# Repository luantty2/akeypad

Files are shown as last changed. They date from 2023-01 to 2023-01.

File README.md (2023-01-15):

# akeypad

8khz polling rate keypad, uses STM32F405 and USB3300, powered by QMK.

This project is just a prototype, cases, plates and other keyboard components are not included.

akeypad

## PCB

pcb_2

## Firmware

The code can be found on my [Fork](https://github.com/luantty2/qmk_firmware/tree/qmk_master_build_2022q4/keyboards/akeypad).

## Bootloader

STM32f405/7xx should comes with a built-in bootloader, but sadly it doesn't seem to work on USB HS interface, if someone uses the default bootloader, he has to manually switch to FS port to upload firmware, then switch back to HS port to use his keyboard.

To address the issue, we can use a mux chip with tinyuf2 bootloader to automatically do that trick, then you don't bother switching port.

The mux chip we used here is TS3USB221, connect its 'S' pin to B14 of STM32. In normal operation, pull the pin to low to select HS interface, in bootloader mode, write this pin to high to select FS interface.

The tinyuf2 bootloader code can be found [here](https://github.com/luantty2/tinyuf2/tree/master_build/ports/stm32f4/boards/akeypad), if you wish to change B14 to other pin, you can modify it in `board.h`.

```c
//--------------------------------------------------------------------+
// Custom GPIO, used for USB mux
//--------------------------------------------------------------------+

#define CUSTOM_GPIO_PORT      GPIOB
#define CUSTOM_GPIO_PIN       GPIO_PIN_14
```

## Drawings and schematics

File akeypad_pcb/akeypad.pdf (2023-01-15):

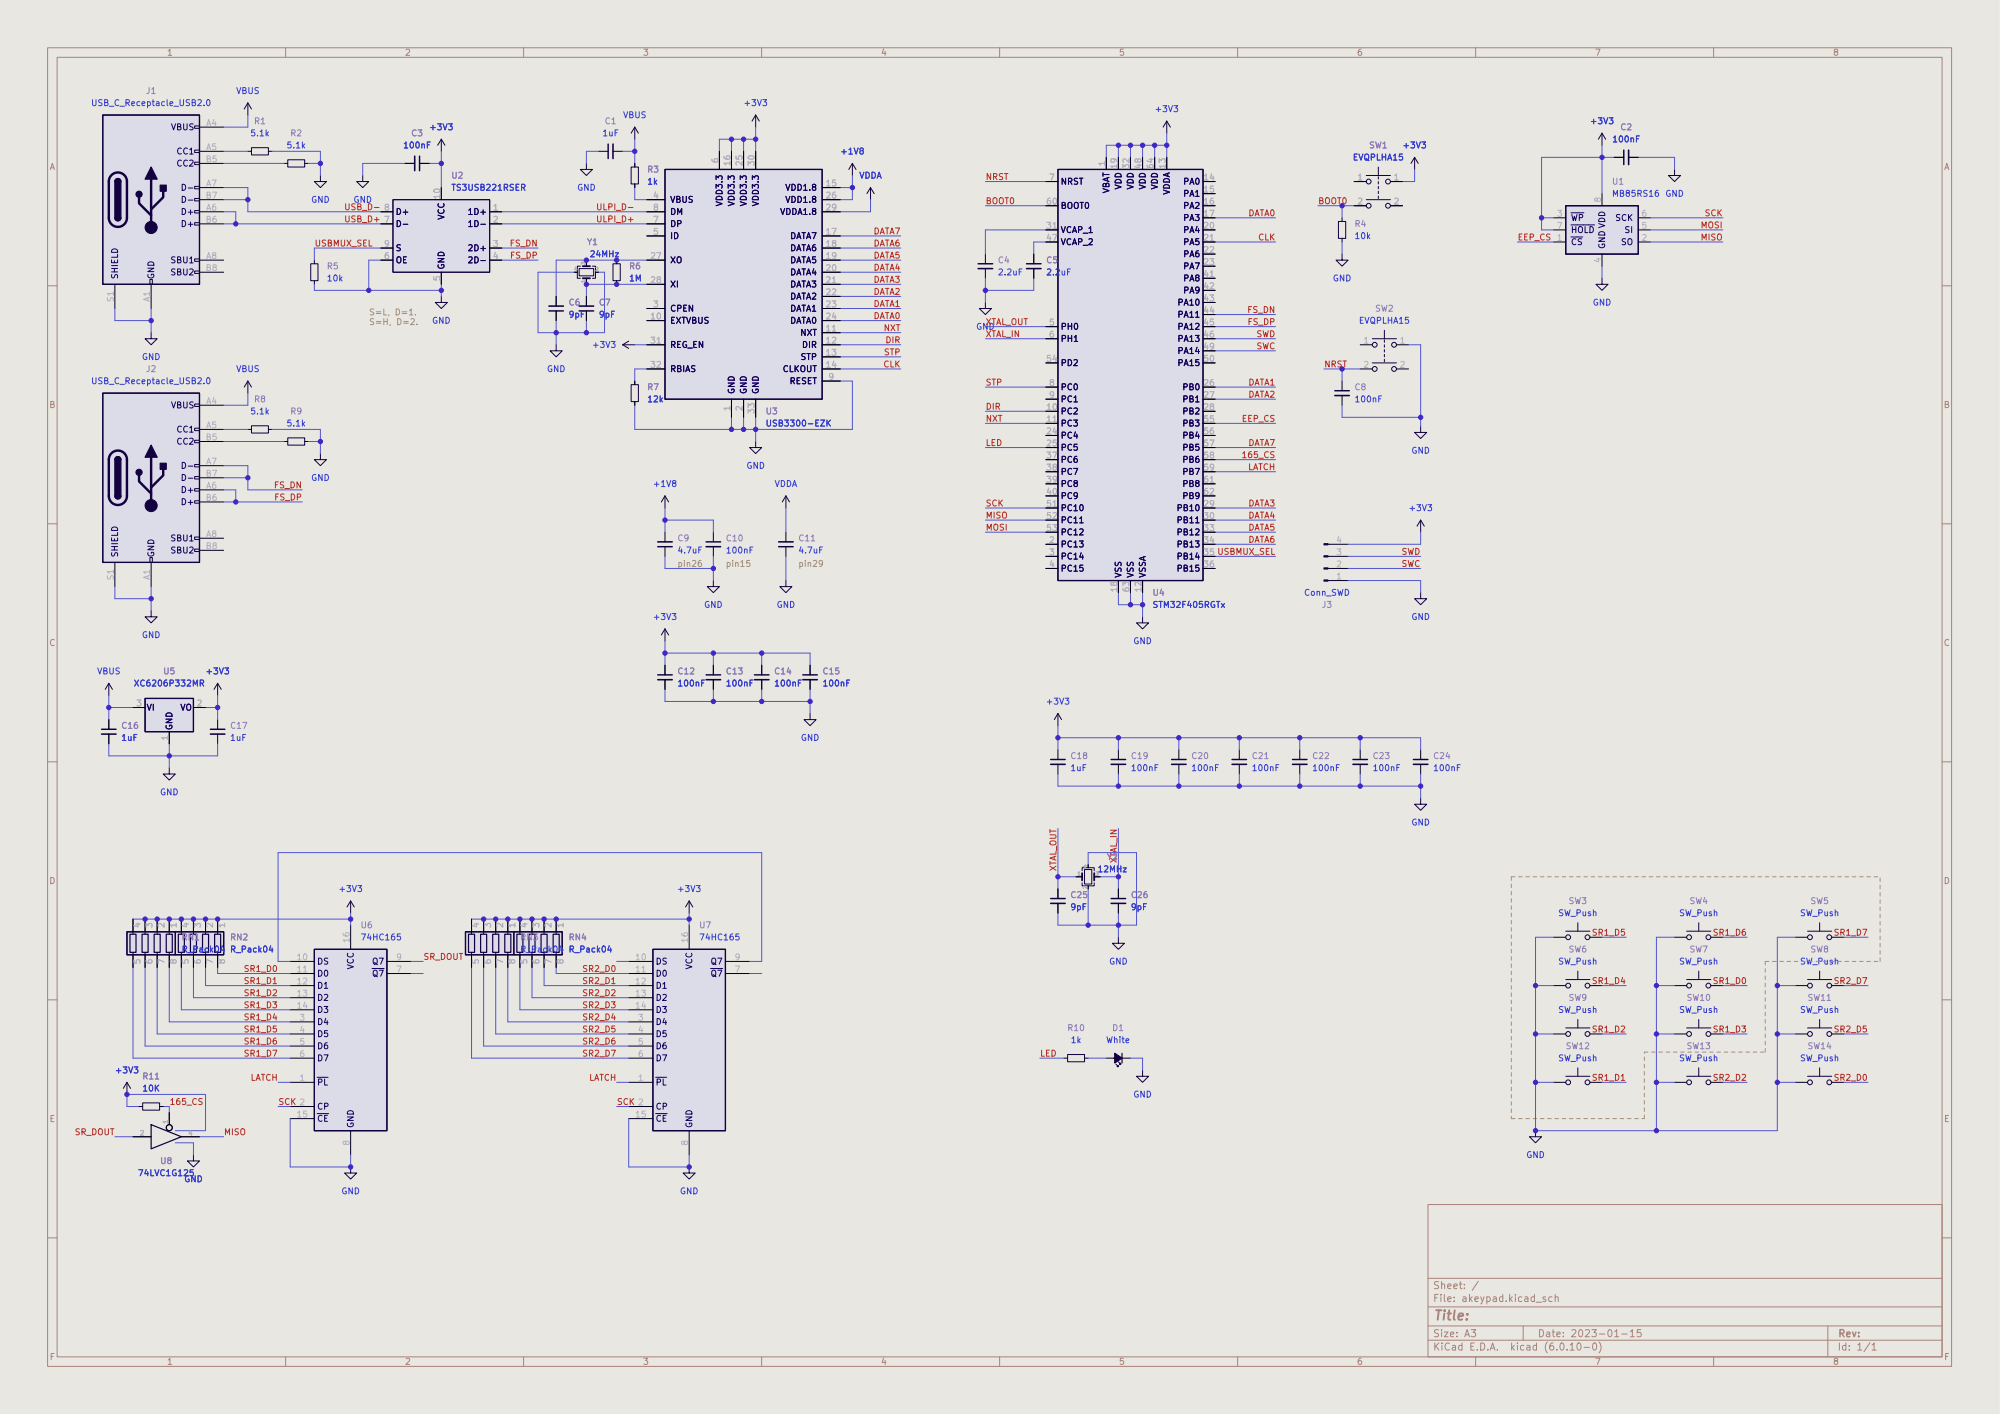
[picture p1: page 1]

1 PC2 10 PC3 11 VSSA 12 VDDA 13 PA0 14 PA1 15 PA2 16 PA3 17 VSS 18 VDD 19 PC13 2 PA4 20 PA5 21 PA6 22 PA7 23 PC4 24 PC5 25 PB0 26 PB1 27 PB2 28 PB10 29 PC14 3 PB11 30 VCAP_1 31 VDD 32 PB12 33 PB13 34 PB14 35 PB15 36 PC6 37 PC7 38 PC8 39 PC15 4 PC9 40 PA8 41 PA9 42 PA10 43 PA11 44 PA12 45 PA13 46 VCAP_2 47 VDD 48 PA14 49 PH0 5 PA15 50 PC10 51 PC11 52 PC12 53 PD2 54 PB3 55 PB4 56 PB5 57 PB6 58 PB7 59 PH1 6 BOOT0 60 PB8 61 PB9 62 VSS 63 VDD 64 NRST 7 PC0 8 PC1 9 U4STM32F405RGTx SR1_D3

1 EXTVBUS 10 NXT 11 DIR 12 STP 13 CLKOUT 14 VDD1.8 15 VDD3.3 16 DATA7 17 DATA6 18 DATA5 19 GND

2 DATA4 20 DATA3 21 DATA2 22 DATA1 23 DATA0 24 VDD3.3 25 VDD1.8 26 XO 27 XI 28 VDDA1.8 29 CPEN 3 VDD3.3 30 REG_EN 31 RBIAS 32 GND 33 VBUS 4

6 DP 7 DM 8 RESET 9 U3USB3300-EZK

6 DP 7 DM 8 RESET 9 VDDA

1 PC2 10 PC3 11 VSSA 12 VDDA 13 PA0 14 PA1 15 PA2 16 PA3 17 VSS 18 VDD 19 PC13 2 PA4 20 PA5 21 PA6 22 PA7 23 PC4 24 PC5 25 PB0 26 PB1 27 PB2 28 PB10 29 PC14 3 PB11 30 VCAP_1 31 VDD 32 PB12 33 PB13 34 PB14 35 PB15 36 PC6 37 PC7 38 PC8 39 PC15 4 PC9 40 PA8 41 PA9 42 PA10 43 PA11 44 PA12 45 PA13 46 VCAP_2 47 VDD 48 PA14 49 PH0 5 PA15 50 PC10 51 PC11 52 PC12 53 PD2 54 PB3 55 PB4 56 PB5 57 PB6 58 PB7 59 PH1 6 BOOT0 60 PB8 61 PB9 62 VSS 63 VDD 64 NRST 7 PC0 8 PC1 9C5

4 SI 5 SCK 6 ~{HOLD} 7 VDD

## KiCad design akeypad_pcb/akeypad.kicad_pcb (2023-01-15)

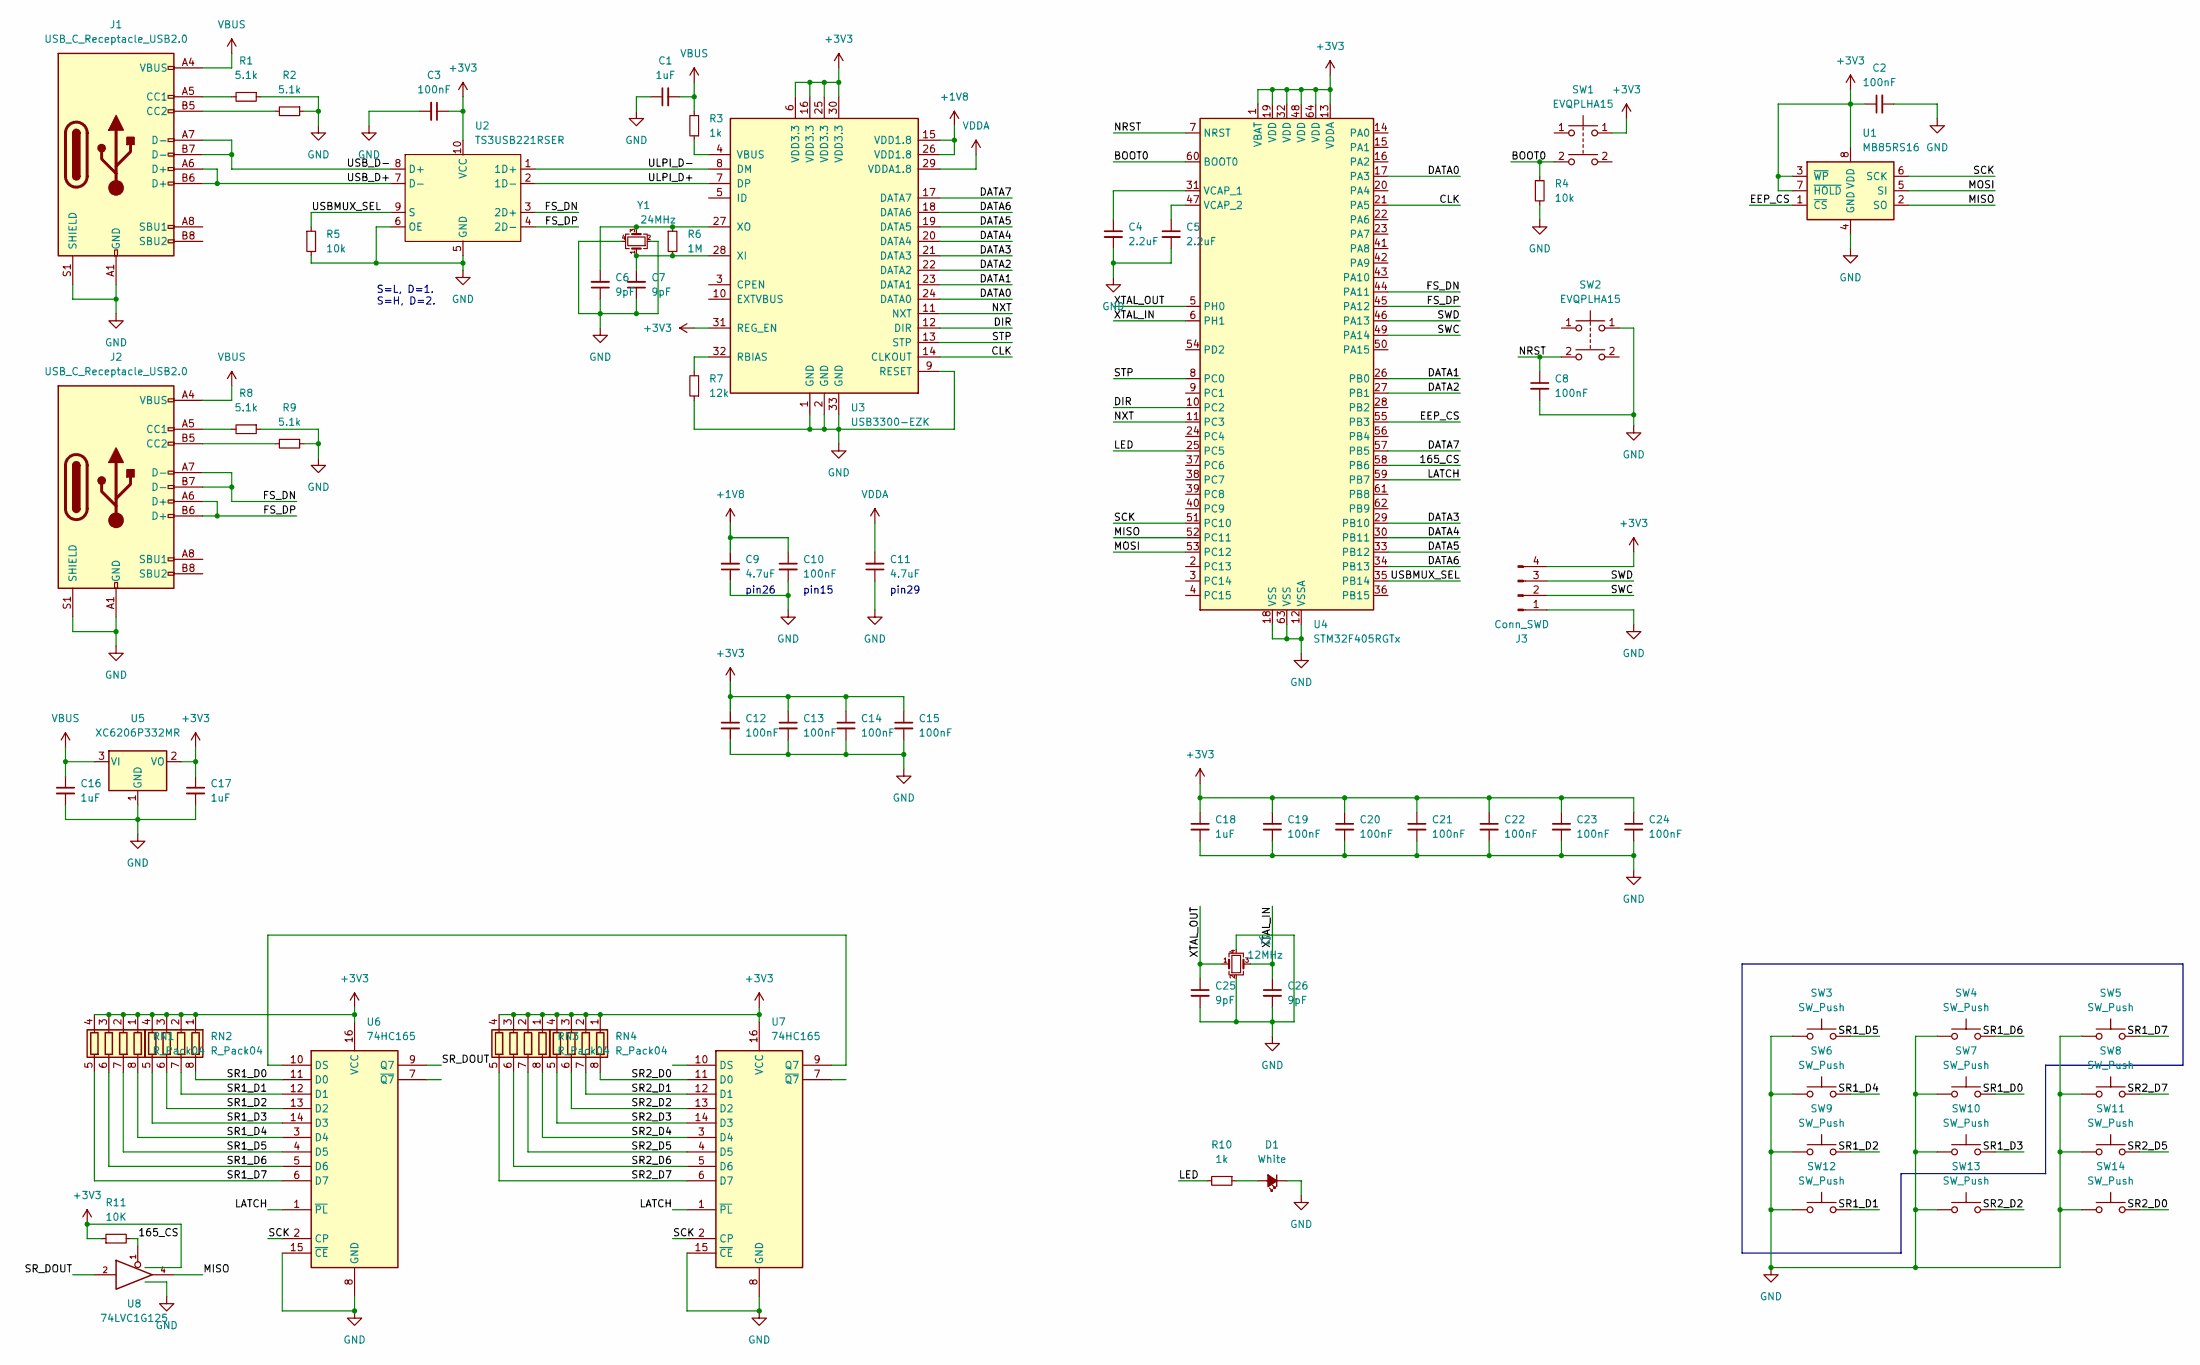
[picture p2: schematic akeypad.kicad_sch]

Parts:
C1, C16, C17, C18: 1uF; C_0603_1608Metric
C2, C3, C8, C10, C12, C13, C14, C15, C19, C20, C21, C22, C23, C24: 100nF; C_0402_1005Metric
C4, C5: 2.2uF; C_0603_1608Metric
C6, C7, C25, C26: 9pF; C_0402_1005Metric
C9, C11: 4.7uF; C_0603_1608Metric
D1: White; LED_0402_1005Metric
J1, J2: USB_C_Receptacle_USB2.0; USB_C_Receptacle_HRO_TYPE-C-31-M-12
J3: Conn_SWD; PinHeader_1x04_P1.27mm_Vertical
R1, R2, R8, R9: 5.1k; R_0402_1005Metric
R3, R10: 1k; R_0402_1005Metric
R4, R5: 10k; R_0402_1005Metric
R6: 1M; R_0402_1005Metric
R7: 12k; R_0402_1005Metric
R11: 10K; R_0402_1005Metric
RN1, RN2, RN3, RN4: R_Pack04; R_Array_Convex_4x0603
SW1, SW2: EVQPLHA15; SW_SPST_Panasonic_EVQPL_3PL_5PL_PT_A15
SW3, SW4, SW5, SW6, SW7, SW8, SW9, SW10, SW11, SW12, SW13, SW14: SW_Push; MXOnly-1U-NoLED
U1: MB85RS16; SOIC-8_3.9x4.9mm_P1.27mm
U2: TS3USB221RSER; UQFN-10
U3: USB3300-EZK; QFN-32-1EP_5x5mm_P0.5mm_EP3.45x3.45mm
U4: STM32F405RGTx; LQFP-64_10x10mm_P0.5mm
U5: XC6206P332MR; SOT-23
U6, U7: 74HC165; SOP-16_3.9x9.9mm_P1.27mm
U8: 74LVC1G125; SOT-23-5
Y1: 24MHz; Crystal_SMD_2016-4Pin_2.0x1.6mm
Y2: 12MHz; Crystal_SMD_3225-4Pin_3.2x2.5mm

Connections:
+1V8: C9.2, C10.1, U3.15 (VDD1.8), U3.26 (VDD1.8)
+3V3: C2.1, C3.1, C12.1, C13.1, C14.1, C15.1, C17.1, C18.1, C19.1, C20.1, C21.1, C22.1, C23.1, C24.1, J3.4, R11.1, RN1.1 (R1.1), RN1.2 (R2.1), RN1.3 (R3.1), RN1.4 (R4.1), RN2.1 (R1.1), RN2.2 (R2.1), RN2.3 (R3.1), RN2.4 (R4.1), RN3.1 (R1.1), RN3.2 (R2.1), RN3.3 (R3.1), RN3.4 (R4.1), RN4.1 (R1.1), RN4.2 (R2.1), RN4.3 (R3.1), RN4.4 (R4.1), SW1.1, U1.3 (~WP), U1.7 (~HOLD), U1.8 (VDD), U2.10 (VCC), U3.6 (VDD3.3), U3.16 (VDD3.3), U3.25 (VDD3.3), U3.30 (VDD3.3), U3.31 (REG_EN), U4.1 (VBAT), U4.13 (VDDA), U4.19 (VDD), U4.32 (VDD), U4.48 (VDD), U4.64 (VDD), U5.2 (VO), U6.16 (VCC), U7.16 (VCC), U8.5 (VCC)
/165_CS: R11.2, U4.58 (PB6), U8.1
/BOOT0: R4.1, SW1.2, U4.60 (BOOT0)
/CLK: U3.14 (CLKOUT), U4.21 (PA5)
/DATA0: U3.24 (DATA0), U4.17 (PA3)
/DATA1: U3.23 (DATA1), U4.26 (PB0)
/DATA2: U3.22 (DATA2), U4.27 (PB1)
/DATA3: U3.21 (DATA3), U4.29 (PB10)
/DATA4: U3.20 (DATA4), U4.30 (PB11)
/DATA5: U3.19 (DATA5), U4.33 (PB12)
/DATA6: U3.18 (DATA6), U4.34 (PB13)
/DATA7: U3.17 (DATA7), U4.57 (PB5)
/DIR: U3.12 (DIR), U4.10 (PC2)
/EEP_CS: U1.1 (~CS), U4.55 (PB3)
/FS_DN: J2.A7 (D-), J2.B7 (D-), U2.3 (2D+), U4.44 (PA11)
/FS_DP: J2.A6 (D+), J2.B6 (D+), U2.4 (2D-), U4.45 (PA12)
/LATCH: U4.59 (PB7), U6.1 (~PL), U7.1 (~PL)
/LED: R10.2, U4.25 (PC5)
/MISO: U1.2 (SO), U4.52 (PC11), U8.4
/MOSI: U1.5 (SI), U4.53 (PC12)
/NRST: C8.1, SW2.2, U4.7 (NRST)
/NXT: U3.11 (NXT), U4.11 (PC3)
/SCK: U1.6 (SCK), U4.51 (PC10), U6.2 (CP), U7.2 (CP)
/SR1_D0: RN2.8 (R1.2), SW7.2, U6.11 (D0)
/SR1_D1: RN2.7 (R2.2), SW12.2, U6.12 (D1)
/SR1_D2: RN2.6 (R3.2), SW9.2, U6.13 (D2)
/SR1_D3: RN2.5 (R4.2), SW10.2, U6.14 (D3)
/SR1_D4: RN1.8 (R1.2), SW6.2, U6.3 (D4)
/SR1_D5: RN1.7 (R2.2), SW3.2, U6.4 (D5)
/SR1_D6: RN1.6 (R3.2), SW4.2, U6.5 (D6)
/SR1_D7: RN1.5 (R4.2), SW5.2, U6.6 (D7)
/SR2_D0: RN4.8 (R1.2), SW14.2, U7.11 (D0)
/SR2_D1: RN4.7 (R2.2), U7.12 (D1)
/SR2_D2: RN4.6 (R3.2), SW13.2, U7.13 (D2)
/SR2_D3: RN4.5 (R4.2), U7.14 (D3)
/SR2_D4: RN3.8 (R1.2), U7.3 (D4)
/SR2_D5: RN3.7 (R2.2), SW11.2, U7.4 (D5)
/SR2_D6: RN3.6 (R3.2), U7.5 (D6)
/SR2_D7: RN3.5 (R4.2), SW8.2, U7.6 (D7)
/SR_DOUT: U6.9 (Q7), U8.2
/STP: U3.13 (STP), U4.8 (PC0)
/SWC: J3.2, U4.49 (PA14)
/SWD: J3.3, U4.46 (PA13)
/ULPI_D+: U2.2 (1D-), U3.7 (DP)
/ULPI_D-: U2.1 (1D+), U3.8 (DM)
/USBMUX_SEL: R5.1, U2.9 (S), U4.35 (PB14)
/USB_D+: J1.A6 (D+), J1.B6 (D+), U2.7 (D-)
/USB_D-: J1.A7 (D-), J1.B7 (D-), U2.8 (D+)
/XTAL_IN: C26.1, U4.6 (PH1), Y2.3
/XTAL_OUT: C25.1, U4.5 (PH0), Y2.1
GND: C1.1, C2.2, C3.2, C4.2, C5.2, C6.1, C7.1, C8.2, C9.1, C10.2, C11.1, C12.2, C13.2, C14.2, C15.2, C16.2, C17.2, C18.2, C19.2, C20.2, C21.2, C22.2, C23.2, C24.2, C25.2, C26.2, D1.1 (K), J1.A1 (GND), J1.A12 (GND), J1.B1 (GND), J1.B12 (GND), J1.S1 (SHIELD), J2.A1 (GND), J2.A12 (GND), J2.B1 (GND), J2.B12 (GND), J2.S1 (SHIELD), J3.1, R1.1, R2.1, R4.2, R5.2, R7.1, R8.1, R9.1, SW2.1, SW3.1, SW4.1, SW5.1, SW6.1, SW7.1, SW8.1, SW9.1, SW10.1, SW11.1, SW12.1, SW13.1, SW14.1, U1.4 (GND), U2.5 (GND), U2.6 (OE), U3.1 (GND), U3.2 (GND), U3.9 (RESET), U3.33 (GND), U4.12 (VSSA), U4.18 (VSS), U4.63 (VSS), U5.1 (GND), U6.8 (GND), U6.15 (~CE), U7.8 (GND), U7.15 (~CE), U8.3 (GND), Y1.2, Y1.4, Y2.2, Y2.4
unnamed: C4.1, U4.31 (VCAP_1)
unnamed: C5.1, U4.47 (VCAP_2)
unnamed: C6.2, R6.1, U3.27 (XO), Y1.3
unnamed: C7.2, R6.2, U3.28 (XI), Y1.1
unnamed: D1.2 (A), R10.1
unnamed: J1.A5 (CC1), R1.2
unnamed: J1.B5 (CC2), R2.2
unnamed: J2.A5 (CC1), R8.2
unnamed: J2.B5 (CC2), R9.2
unnamed: R3.1, U3.4 (VBUS)
unnamed: R7.2, U3.32 (RBIAS)
unnamed: U6.10 (DS), U7.9 (Q7)
VBUS: C1.2, C16.1, J1.A4 (VBUS), J1.A9 (VBUS), J1.B4 (VBUS), J1.B9 (VBUS), J2.A4 (VBUS), J2.A9 (VBUS), J2.B4 (VBUS), J2.B9 (VBUS), R3.2, U5.3 (VI)
VDDA: C11.2, U3.29 (VDDA1.8)

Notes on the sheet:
pin15
pin26
pin29
S=L, D=1. S=H, D=2.

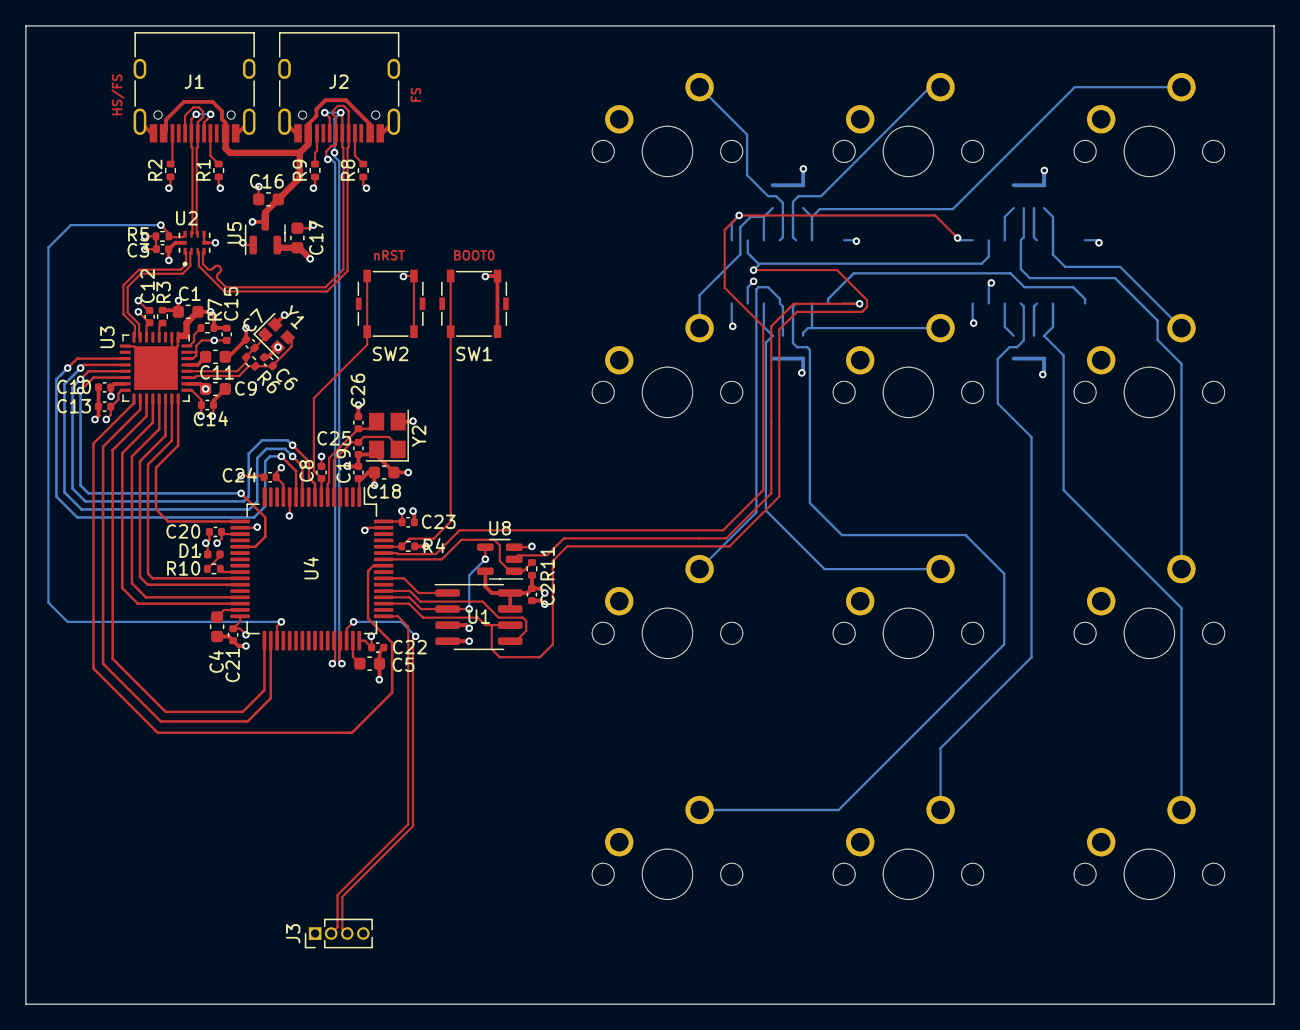
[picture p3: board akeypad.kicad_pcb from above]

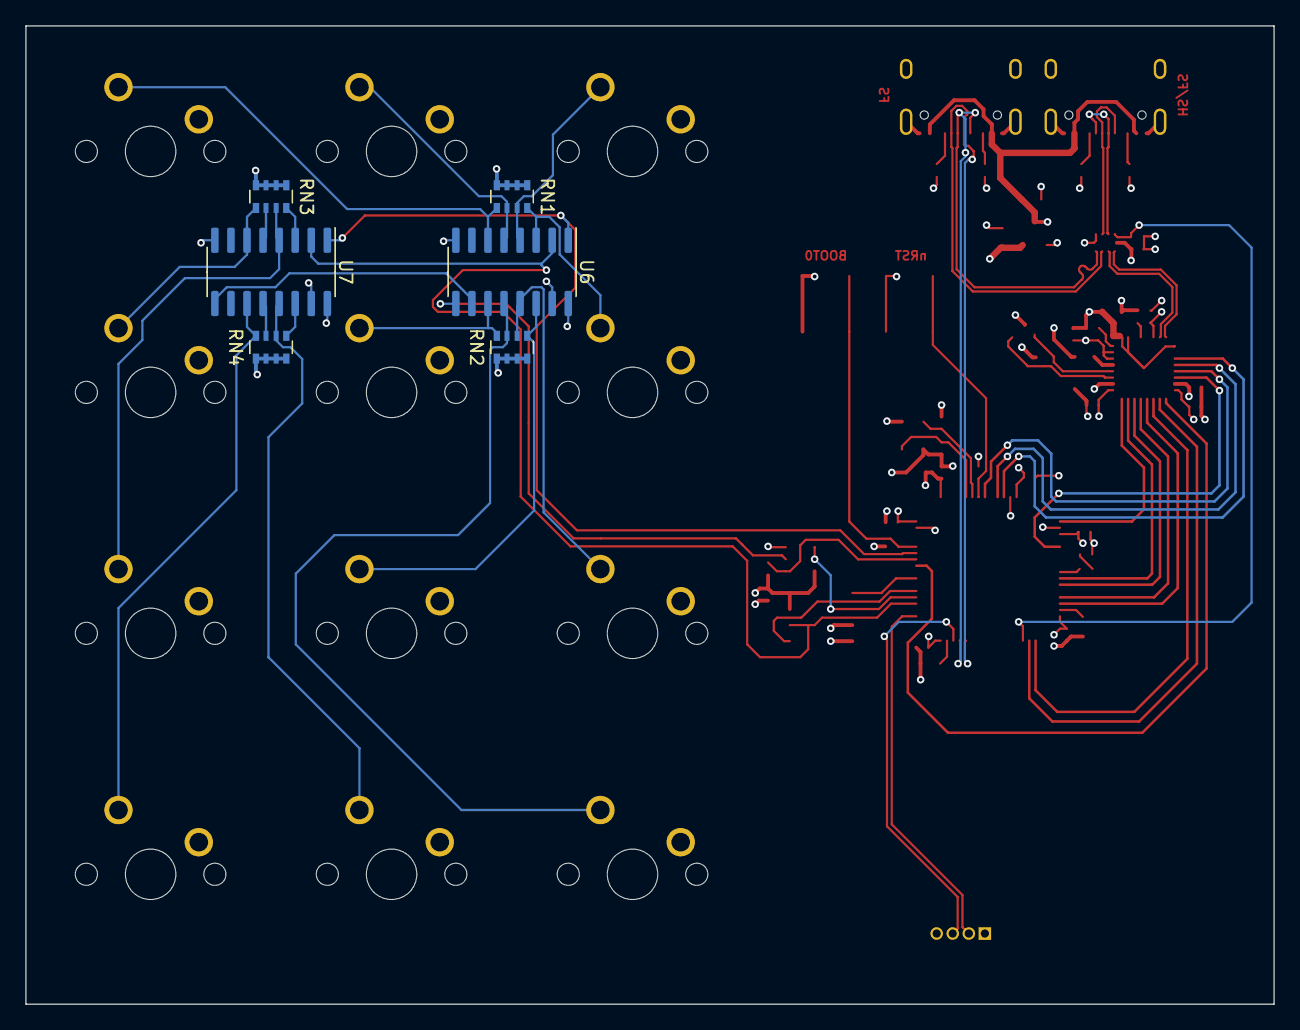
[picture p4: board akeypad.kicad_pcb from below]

Board: 4 copper layers, 98.7 x 77.3 mm, 69 parts (6 on the bottom side), 66 nets.

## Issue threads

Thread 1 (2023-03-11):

STM32F446 + USB3320

Xelus22, 2023-03-11:
Hi Luantty, im not sure where else to communicate to you. But is it possible to get a STM32F446 config? I've been testing to try with the USB OTG HS but i am unsuccessful. :(

luantty2, 2023-03-12:
How does your [board.h](https://github.com/luantty2/qmk_firmware/blob/qmk_master_build_2022q4/keyboards/akeypad/board.h) file look like?
OTG HS won't work without `D0-D7, CK, STP, DIR, NXT` pins defined, so that's pretty much all the config you need.

Xelus22, 2023-03-14:
OK thanks ill have to try on the weekend. :)

Xelus22, 2023-07-02:
Hi Luantty, sorry I haven't had time to do this until now. (yes a very long time)

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

Ive found that the STM32F446 uses a slightly different Alternate value for the D4 pin.

How should i edit the board.h to reflect this?

luantty2, 2023-07-06:
Hi,
I haven't looked too deep into your config, but generally looks correct and should work.
There might be a hardware issue that stops it from working?
